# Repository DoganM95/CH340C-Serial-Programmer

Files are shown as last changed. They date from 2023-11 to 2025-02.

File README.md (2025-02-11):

# Intro

This Module is a specialized ESP32 programmer that simplifies the programming process by incorporating auto-programming functionality. This means there's no need for manual interaction with the ESP32 during programming, such as pressing buttons on the board. Additionally, it supports Power Delivery (PD), allowing the attached ESP32 to be powered from a PD source at 5V.

## Visual Overview

<table>
  <tr>
    <td>
      PCB Top View
    </td>
    <td>
      PCB Bottom View
    </td>
    <td>
      PCBWay order raw
    </td>
    <td>
      PCBWay order assembled
    </td>
  </tr>
</table>

## Key Features

- **Compact Design**: The module is designed to occupy minimal space, making it ideal for streamlined setups.
- **Power Delivery Support**: Compatible with Power Delivery, enabling the ESP32 to run directly from a 5V PD source.
- **USB-C Connectivity**: Utilizes a USB-C connection for modern, reversible, and reliable connectivity.
- **Auto-Programming**: Simplifies the programming process by eliminating the need for manual button presses on the ESP32 during programming.

## BOM

The parts are listed in the recommended order of soldering.

| Reference | Part Name | Description |
|---|---|---|
| J1 | CQ-USB-C16PSMT01 | 16 Pin female USB C connector | 
| U2 | CH340C | Programming IC, SOP-16 package |
| R1 | 0603-5.1k | Resistor, 0603 sized, 5.1 kilo Ohm |
| R2 | 0603-5.1k | Resistor, 0603 sized, 5.1 kilo Ohm |
| C1 | 0603-100nF | Capacitor, 0603 sized, 100 nano Farad |
| C2 | 0603-4.7uF | Capacitor, 0603 sized, 4.7 micro Farad |
| JP1 | Jumper | short: mid (VCC) with left/inner (3V3) or right/outer (5V)|
| U4 | AO3400 | N-Channel Mosfet, SOT-23 package |
| U3 | AO3400 | N-Channel Mosfet, SOT-23 package |
| U1 | AMS1117 3.3V | 5V to 3.3V Voltage regulator, SOT-223 package |

## Driver
https://wch.cn/download/CH341SER_ZIP.html

## Key Takeaways
- The CH340C can be powered with `3.3V` or `5V`. The input Voltage translates to its TX voltage and 5V is too high for e.g. an esp32, so it gets powered with `3.3V` 
- The `3V` pin of the CH340C needs to be connected to `GND` with a `100nF` capacitor, else it will not work and not show up in device manager
- Connecting it with wrong polarity (`5V` and `GND`) gets the chip hot quickly, but doesn't break it when cutting the power off soon (like 20 seconds)
- The minimum circuit, only to check if a CH340C ic is functional, consists of a usb port with (`5V`, `D-`, `D+`, `GND`) connected to the CH340C as well as the said `100nF` capacitor from its `3V` pin to `GND`
- The capacitor (`C2`) between `EN` and `GND` needs to be high enough, else the auto reset will not work. `100nF` was too little, so the IDE was stuck at `Hard resetting via RTS pin...` and the module had to be plugged out and in again manually. Increasing the capacitance to `4.7uF` solved this and the auto reset works fine with that.

## Video preview
https://github.com/DoganM95/CH340C-Pcb/assets/38842553/810827a4-b2fa-454a-bed7-59ae43e08667

## Sponsorship - [PCBWay](https://pcbway.com/g/8bcMJY)
The physical PCB's and stencil are sponsored by [PCBWay](https://pcbway.com/g/8bcMJY).  
Overall i am very satisfied with the quality of the pcb's, especially with
- the matte surface finish
- the cover of the vias, which almost feel like plugged, so there is no way to accidentally put solder in there to cause a short circuit
- the traces, which are covered better than other manufacturers do and cannot be brushed/scraped away easily. Big plus for that

One thing i missed was clearer texts (white) on the pcb's, but printing those in good quality, especially sized at 0.6mm, can be challenging.  
I am very pleased to get these sponsored by [PCBWay](https://pcbway.com/g/8bcMJY) and can recommend their service, especially for the high quality you get and the huge amount of configurable settings.

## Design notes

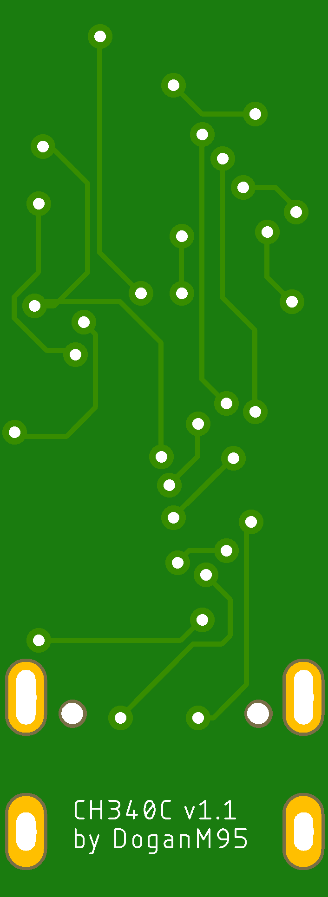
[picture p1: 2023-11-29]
assets/ch340c_esp32_bottom.png

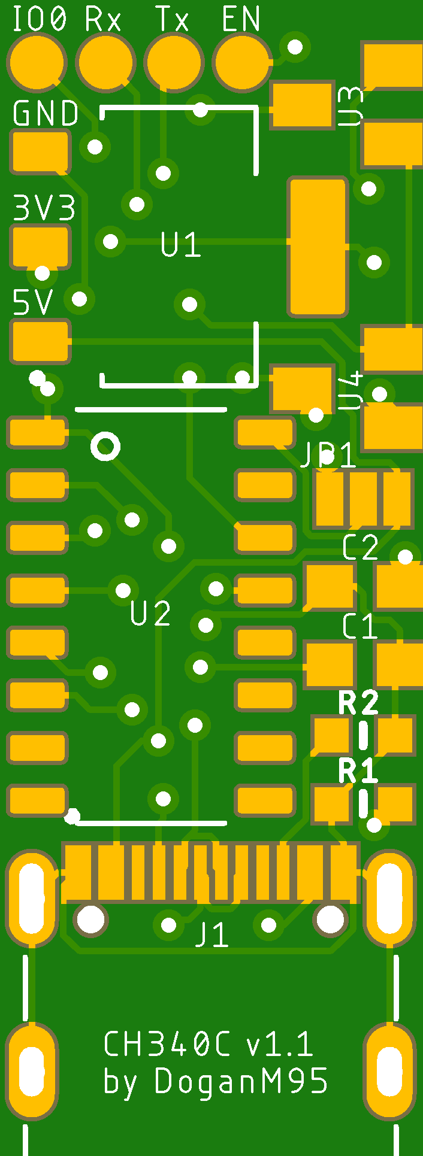
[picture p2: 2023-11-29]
assets/ch340c_esp32_top.png

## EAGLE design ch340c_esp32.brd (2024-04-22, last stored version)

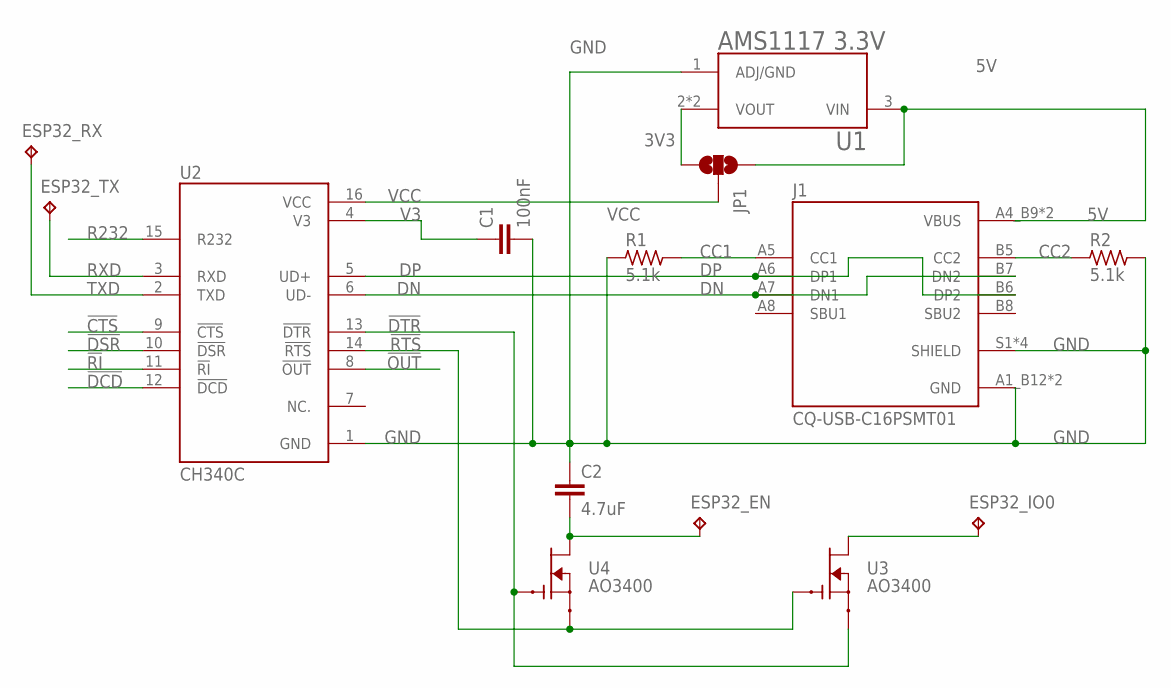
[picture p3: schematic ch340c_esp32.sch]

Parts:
C1: 100nF; C0603
C2: 4.7uF; C0603
ESP32_EN, ESP32_IO0, ESP32_RX, ESP32_TX: TPB1,27; B1,27
J1: CQ-USB-C16PSMT01; SHENZHEN-CHUANGQIN-TECHNOLOGY_CQ-USB-C16PSMT01
JP1: JUMPER-SMT_3_NO_NO-SILK; SMT-JUMPER_3_NO_NO-SILK
R1, R2: 5.1k; RC-MASTER-SMD_R0603MP
U1: AMS1117 3.3V; SOT229P700X180-4N
U2: CH340C; SOIC127P600X180-16N
U3, U4: AO3400; SOT23

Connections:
3V3: JP1.1, U1.2 (VOUT), U1.4 (VOUT)
5V: J1.A4_B9 (VBUS), J1.B4_A9 (VBUS), JP1.3, U1.3 (VIN)
!CTS: U2.9 (!CTS)
!DCD: U2.12 (!DCD)
!DSR: U2.10 (!DSR)
!DTR: U2.13 (!DTR), U3.2 (S), U4.1 (G)
!OUT: U2.8 (!OUT)
!RI: U2.11 (!RI)
!RTS: U2.14 (!RTS), U3.1 (G), U4.2 (S)
CC1: J1.A5 (CC1), R1.2
CC2: J1.B5 (CC2), R2.1
DN: J1.A7 (DN1), J1.B7 (DN2), U2.6 (UD-)
DP: J1.A6 (DP1), J1.B6 (DP2), U2.5 (UD+)
EN: C2.2, ESP32_EN.TP, U4.3 (D)
GND: C1.2, C2.1, J1.A1_B12 (GND), J1.B1_A12 (GND), J1.S1 (SHIELD), J1.S2 (SHIELD), J1.S3 (SHIELD), J1.S4 (SHIELD), R1.1, R2.2, U1.1 (ADJ/GND), U2.1 (GND)
IO0: ESP32_IO0.TP, U3.3 (D)
R232: U2.15 (R232)
RXD: ESP32_TX.TP, U2.3 (RXD)
TXD: ESP32_RX.TP, U2.2 (TXD)
V3: C1.1, U2.4 (V3)
VCC: JP1.2, U2.16 (VCC)

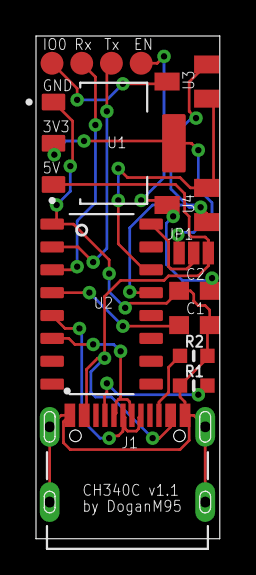
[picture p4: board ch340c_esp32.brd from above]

Board: 2 copper layers, 10.2 x 27.9 mm, 14 parts (0 on the bottom side), 15 nets.

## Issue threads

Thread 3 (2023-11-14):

Improve pads

DoganM95, 2023-11-14:
Make pads smaller and add 3v3, 4v and gnd pad, so esp can get everything it needs to run out of this board.

DoganM95, 2023-11-14:
Adding labels to nearby ams1117 should be sufficient
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

Closed 2023-11-15.

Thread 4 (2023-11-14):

Fix traces

DoganM95, 2023-11-14:
Some traces are exposed to to nearby pad contact. Move traces a bit until fully masked.

Closed 2023-11-15.

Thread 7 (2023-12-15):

Shrink schematic

DoganM95, 2023-12-15:
Current schematic can be compressed by pulling up the esp pins at the left and by moving the lower mosfet to the right. That way, the preview image would become more compact and more readable

Closed 2024-05-17.

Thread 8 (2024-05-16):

Quick question about the V3 pin

HankLloydRight, 2024-05-16:
First, thanks for this design, very helpful! Thank you.

I'm trying to integrate this on my own custom PCB with the ESP32-WROOM, but I find conflicting information about the V3 pin #4.

In your design, you have V3 going to a 100nF cap to ground, which many CH340C designs have when powering with a 3.3v source on VCC.

But in the datasheet for CH304C, it says:  "_When using 3.3V power voltage, connects V3 with VCC, both input 3.3V power voltage, and the other circuit voltage which connected with CH340 cannot exceed 3.3V_" which is what I'm doing, because that's how the LOLIND32 dev board has, which is what I based my design off of (see: https://www.wemos.cc/en/latest/_static/files/sch_d32_v1.0.0.pdf )

So why the discrepancy with V3, and what difference does it create?   My circuit is drawing nearly 800ma which is more than twice it should be pulling, I'm wondering if it's because I have VCC and V3 tied together like the datasheet says.

thank you.

DoganM95, 2024-05-17:
As far as i remember on the 3V pin:
- Leaving it floating: Windows device manager fails to recognize the hardware
- Connecting to GND with 100nF in between: worked fine (see readme section 'Takeaways")
- Connecting it to VCC (3.3Volt): forgot the outcome, but the bigger the voltage difference bewteen your 3.3V power source (AMS1117 in my case) and the 3V pin, the more current will be drawn, since the higher voltage tries to "chagre" the lower one until equilibrium is reached i guess

However, according to chatGPT:
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

I chose to not use the 3V pin as a power source anyway, and the 100nF cap to GND fixed any connectivity issues.
Powering the system via USB ch340c running only a loop printing "hello world" every second, it draws less than 10mA, since the USB meter shows 0.00A.

Hope this info is somewhat helpful to you

HankLloydRight, 2024-05-17:
That's really helpful, thank you. Since I currently have VCC connected to the 3V pin, the voltages at both are obviously the same, but your explanation causing higher current sounds possible and what might be happening to me now.

And I don't need to use the 3V pin as a power source, as I have a 3V3 rail on my board already (also from a AMS1117-33).

But I'm not sure I can get in there with my iron to pluck off just pin #4 in order to add a cap and ground it to see if my over-current problem goes away.

Closed 2025-02-10.

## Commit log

2023-11-14 add unrouted preview
    [ch340c_esp32.brd]
2023-11-15 resolve issues
    [ch340c_esp32.brd]
2023-11-28 prototype v1.1
    [ch340c_esp32.brd, ch340c_esp32.sch]
2023-11-29 route airwires for v1.1
    [ch340c_esp32.brd]
2023-11-29 Update BOM
2023-12-08 fix BOM
2023-12-08 update C2 cap value
    [ch340c_esp32.brd, ch340c_esp32.sch]
2023-12-12 quick schematic cleanup
    [ch340c_esp32.sch]
2023-12-12 add schematic
2024-04-22 optimize schematic
    [ch340c_esp32.brd, ch340c_esp32.sch]

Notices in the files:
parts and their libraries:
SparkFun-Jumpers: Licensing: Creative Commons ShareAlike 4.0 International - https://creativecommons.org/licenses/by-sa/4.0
